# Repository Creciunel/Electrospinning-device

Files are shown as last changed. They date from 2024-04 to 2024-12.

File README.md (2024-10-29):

<h2>Contents</h2>

<ul>
  <li><a href="#features">Features</a></li>
  <li><a href="#hardware-setup">Hardware Setup</a></li>
  <li><a href="#software-board-code">Software Board Code</a></li>
  <li><a href="#usage">Usage</a></li>
  <li><a href="#contributing">Contributing</a></li>
  <li><a href="#license">License</a></li>
</ul>

<h1>Electrospinning Device based on ATMEGA2560</h1>

<p>This repository contains the source code, hardware schematics, and documentation for a device designed to facilitate the electrospinning process using the ATMEGA2560 microcontroller (Arduino Mega).</p>

<h2 id="features">Features</h2>

<p>The device provides the following features:</p>
<ul>
  <li>Control and monitoring with BME280 sensor of temperature, pressure, humidity. And adjustable flow rate.</li>
  <li>FreeRTOS based task scheduler for easier and more efficient task management.</li>
  <li>High voltage source for electrospinning process.</li>
  <li>LCD display for monitoring.</li>
  <li>Motor for controlling the flow of the syringe. using driver TB6600.</li>
  <li>Encoder for user interaction.</li>
</ul>

<h2 id="hardware-setup">Hardware Setup</h2>

<table>
  <tr>
    <th>
      <p>The hardware setup consists of the following components:</p>
    </th>
  <tr>
    <td>
      <ul>
        <li><b>The high voltage power supply</b> generates the high voltage needed for the electrospinning process. It provides a stable and adjustable voltage source to create the electrostatic field required to draw the polymer solution into nanofibers.</li>
        <li><b>Varistor and Transformer</b> convert the high voltage to the voltage required for electrospinning.</li>
        <li><b>Multiplier/Rectifier</b> converts the voltage to the voltage required for the motor.</li>
      </ul>
    </td>
  </tr>
  <tr>
    <td>
      <h3>Comand Board</h3>
        <ul>
        <li><b>MCU</b> ATMEGA2560 (Mega 2560)</li>
        <li><b>Encoder</b> For seting the flow rate, starting and stopping the motor, and opening screen with sensor values.</li>
        <li><b>LCD Display</b> Show sensor values.</li>
        <li><b>TB6600</b> Stepper motor driver.</li>
        <li><b>Motor</b> Stepper motor for controlling the flow of the syringe.</li>
        <li><b>BME280</b> Sensor for monitoring temperature, pressure, and humidity.</li>
        <li><b>Power Supply</b> MCU power supply.</li>
      </ul>
    </td>
  </tr>
</table>
<ul>
  <li>See more about <a href="/Hardware/README.md">hardware Setup</a></li>
</ul>

<h2 id="software-board-code">Software Board Code</h2>
<ul>
  <li>See more about <a href="/Software/Electrospining/README.md">software board code.</a></li>
</ul>

<h2>Usage</h2>

<p>To use the electrospinning device:</p>
<ol>
  <li>Connect the high voltage source to 220V.</li>
  <li>Connect the Arduino Mega to the components and upload the provided source code.</li>
  <li>Use the LCD screen with encoder to control and monitor the electrospinning process.</li>
  <li>Adjust the settings as needed and start the electrospinning process.</li>
  <li>Monitor the output and make adjustments as necessary.</li>
</ol>

<h2>Contributing</h2>
<p>Contributions to this project are welcome. Please fork the repository, make your changes, and submit a pull request.</p>

<h2>License</h2>
<p>This project is licensed under the <a href="LICENSE">MIT License</a>.</p>

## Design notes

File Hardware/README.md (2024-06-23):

# Electrospinning Device based on Arduino Mega

## High voltage result and schematics

### Reult

<p> The result of the electrospinning process is accesible on link below. </p>
<a href="https://docs.google.com/spreadsheets/d/1FEkuDaI_2rEFF1M06S9z06Yd7cQ-smT4pYeCvJsIN_U/edit?usp=sharing">Value on testing process</a>

### Schematics

## Hardware Connection

<table style="border: none;">
  <tr>
    <h3>Display</h3>
    <!-- display charaters -->
    <ul>
        <li> Examples of <a href="https://github.com/WeActStudio/WeActStudio.TFT-LCD-Module/tree/master/Examples">code</a> </li>
        <li> <a href="https://github.com/WeActStudio/WeActStudio.TFT-LCD-Module">WeActStudio.TFT-LCD-Module</a> </li>
    </ul>
    <td style="border: none; text-align: left;">
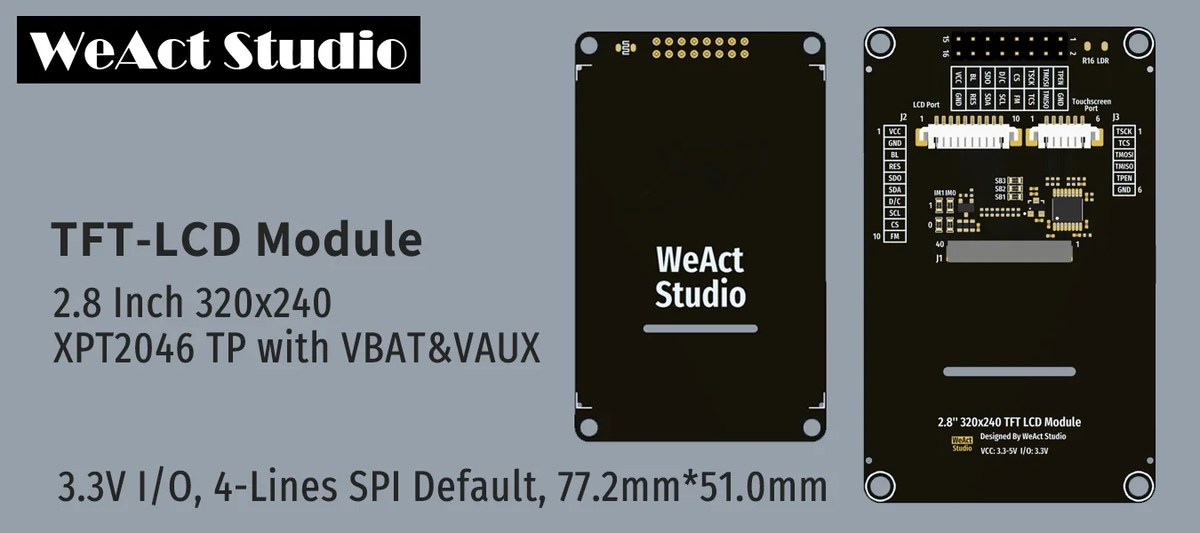
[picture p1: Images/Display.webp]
Display
      
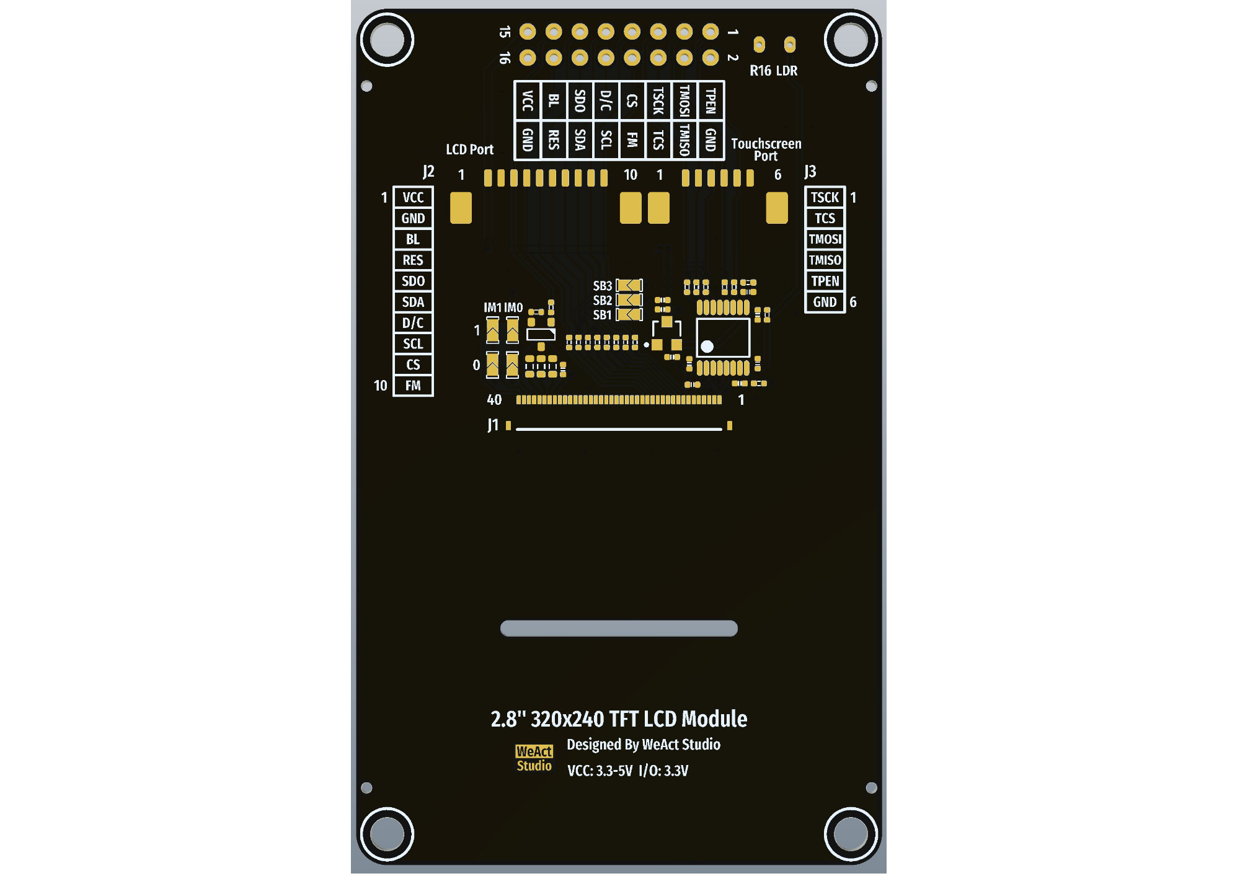
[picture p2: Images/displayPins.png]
pinout
      
      <!-- https://github.com/WeActStudio/WeActStudio.TFT-LCD-Module -->
      <table>
        <tr>
            <th>Arduino Pins</th>
            <th>ILI9341 Pins</th>
            <th></th>
            <th>Arduino Pins</th>
            <th>TouchScreen Pins</th>
        </tr>
        <tr>
            <td>3.3V or 5V</td>
            <td>VCC</td>
            <td></td>
            <td>13</td>
            <td>TSCK (SCK)</td>
        </tr>
        <tr>
            <td>GND</td>
            <td>GND</td>
            <td></td>
            <td>14</td>
            <td>TCS (CS)</td>
        </tr>
        <tr>
            <td>6</td>
            <td>BL</td>
            <td></td>
            <td>15</td>
            <td>TMOSI (MOSI)</td>
        </tr>
        <tr>
            <td>7</td>
            <td>RES</td>
            <td></td>
            <td>12</td>
            <td>TMISO (MISO)</td>
        </tr>
        <tr>
            <td>12</td>
            <td>SDO (MISO)</td>
            <td></td>
            <td>17</td>
            <td>TPEN (Touch Interrupt)</td>
        </tr>
        <tr>
            <td>11</td>
            <td>SDA (MOSI)</td>
            <td></td>
            <td>GND</td>
            <td>GND</td>
        </tr>
        <tr>
            <td>8</td>
            <td>D/C</td>
            <td></td>
            <td></td>
            <td></td>
        </tr>
        <tr>
            <td>13</td>
            <td>SCL (SCK)</td>
            <td></td>
            <td></td>
            <td></td>
        </tr>
        <tr>
            <td>9</td>
            <td>CS</td>
            <td></td>
            <td></td>
            <td></td>
        </tr>
        <tr>
            <td>Not connected</td>
            <td>FM</td>
            <td></td>
            <td></td>
            <td></td>
    </table>
 <!-- <table>
    <tr>
          <th>Arduino Pins</th>
          <th>ILI9341 Pins</th>
        </tr>
        <tr>
          <td>53</td>
          <td>TFT_CS</td>
        </tr>
        <tr>
          <td>46</td>
          <td>TFT_DC</td>
        </tr>
        <tr>
          <td>51</td>
          <td>TFT_MOSI</td>
        </tr>
        <tr>
          <td>52</td>
          <td>TFT_SCLK</td>
        </tr>
        <tr>
          <td>47</td>
          <td>TFT_RST</td>
        </tr>
        <tr>
          <th>Arduino Pins</th>
          <th>TouchScreen Pins</th>
        </tr>
        <tr>
          <td>A14</td>
          <td>YP</td>
        </tr>
        <tr>
          <td>A15</td>
          <td>XM</td>
        </tr>
        <tr>
          <td>48</td>
          <td>YM</td>
        </tr>
        <tr>
          <td>49</td>
          <td>XP</td>
        </tr>
      </table> -->
    </td>
  </tr>

  <tr>
    <h3>Motor</h3>
    <td style="border: none; text-align: left;">
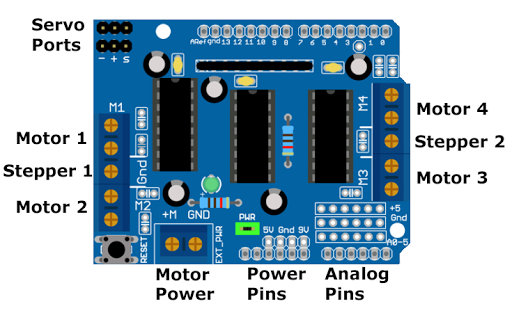
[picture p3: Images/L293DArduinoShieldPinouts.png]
L293D Motor Driver Shield
          
      <table>
        <tr>
          <th>Arduino Pins</th>
          <th><a href="https://github.com/adafruit/Adafruit_Motor-Shield-v1/blob/master/mshieldv12schem.png">L293D Motor Driver Shield</a></th>
          <th></th>
          <th>Motor sheld sheft registers 74HCT595</th>
          <th>Pin</th>
        </tr>
        <tr>
          <td>11</td>
          <td>Motor 1</td>
          <td></td>
          <td>MOTOR1_A</td>
          <td>2</td>
        </tr>
        <tr>
          <td>3</td>
          <td>Motor 2</td>
          <td></td>
          <td>MOTOR1_B</td>
          <td>3</td>
        </tr>
        <tr>
          <td>5</td>
          <td>Motor 3</td>
          <td></td>
          <td>MOTOR2_A</td>
          <td>1</td>
        </tr>
        <tr>
          <td>6</td>
          <td>Motor 4</td>
          <td></td>
          <td>MOTOR2_B</td>
          <td>4</td>
        </tr>
        <tr>
          <td>9</td>
          <td>Servo 1</td>
          <td></td>
          <td>MOTOR3_A</td>
          <td>5</td>
        </tr>
        <tr>
          <td>10</td>
          <td>Servo 2</td>
          <td></td>
          <td>MOTOR3_B</td>
          <td>7</td>
        </tr>
        <tr>
          <td>4, 7, 8, 12</td>
          <td>Shift registers</td>
          <td></td>
          <td>MOTOR4_A</td>
          <td>0</td>
        </tr>
        <tr>
          <td>2 and 13, Analog A0 to A5</td>
          <td>Not Connected</td>
          <td></td>
          <td>MOTOR4_B</td>
          <td>6</td>
        </tr>
      </table>

### ADC Analog-to-Digital Converter

It is connected to pin A8 or as number 62.

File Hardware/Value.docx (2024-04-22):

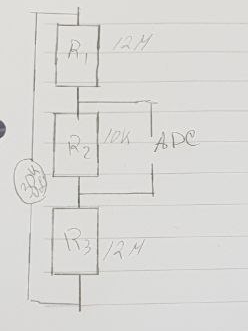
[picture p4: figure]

V_(out) = 30kV

V_(in) = 24V A_(in) = 6.25A P = 150W

P = I^2 ·R

I_(tot) = 30kV/200Mῼ = 150µA

P_1 =P_3 = (150 µA )^2 · 100Mῼ = 2.25W

P_2 = (150 µA )^2 · 10kῼ = 225µW

V_(R1) = 150 µA · 100Mῼ = 15V

V_(R2) = 150 µA · 10kῼ = 1.5V

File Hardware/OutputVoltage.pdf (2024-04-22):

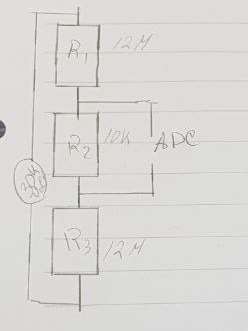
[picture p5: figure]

V= 30kV

V= 24V A= 6.25A P = 150W

P = I

- R
I= 30kV/200Mῼ = 150µA

P = P= (150 µA )
- 100Mῼ = 2.25W

P= (150 µA )
- 10kῼ = 225µW

V= 150 µA · 100Mῼ = 15V

V= 150 µA · 10kῼ = 1.5V

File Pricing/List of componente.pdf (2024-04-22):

NR | What we actual have | Price
1 | Arduino Mega | | Zero - from diferent project
2 | ZVS Driver | mkrid=707-127634-2357-0&ssspo=ux51k_mbsss&sssrc=4429486&ssuid=lz6subesszy&var= | 11.91 Euro - with Postage
3 https://sl.aliexpress.ru/p?key=gbbROf2 | ILI9341 Display | | 205 Lei - with Postage
4 https://sl.aliexpress.ru/p?key=QlbROZx | L293D Sheeld driver | | 64 Lei - with Postage
5 | Rezistors
6 | Steper Motoare
7 From old TV | FlyBack Transformer
8 | Source
9

Vlad
Cătălin

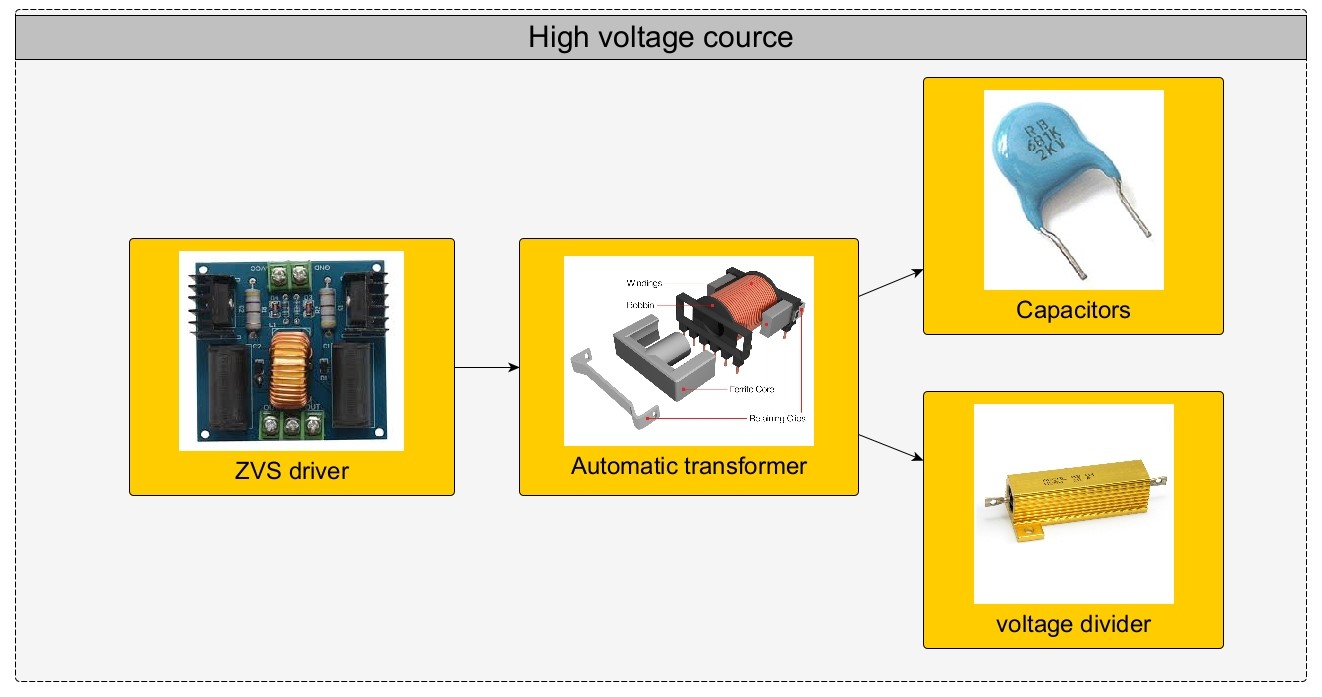
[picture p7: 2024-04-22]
Images/HVS.jpg

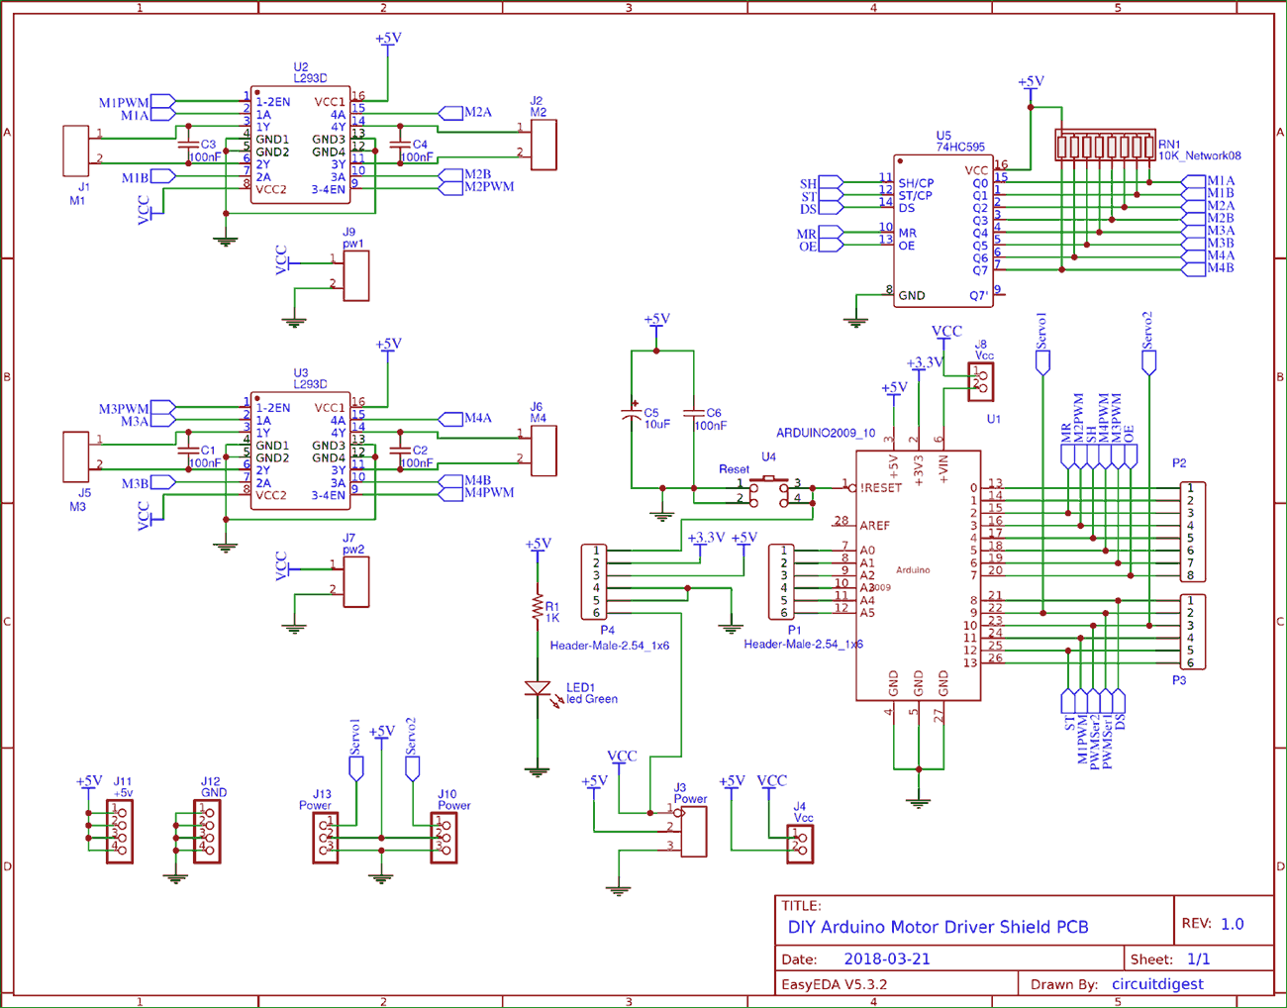
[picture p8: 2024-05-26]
Images/Circuit-Diagram-for-DIY-Arduino-Motor-Driver-Shield-PCB_0.png

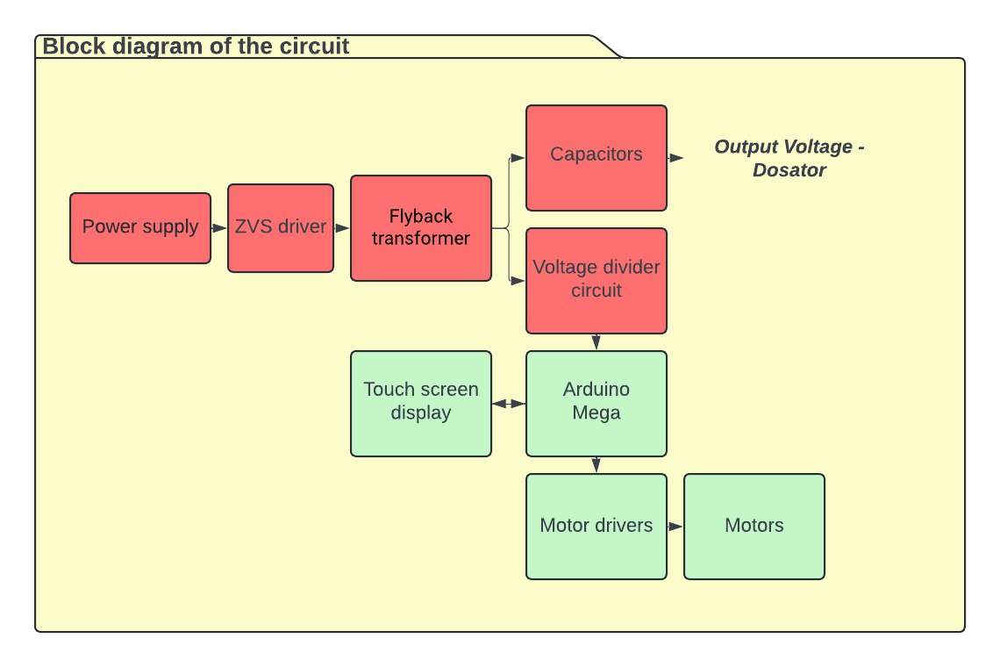
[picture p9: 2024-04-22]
Images/Block-diagram.jpg

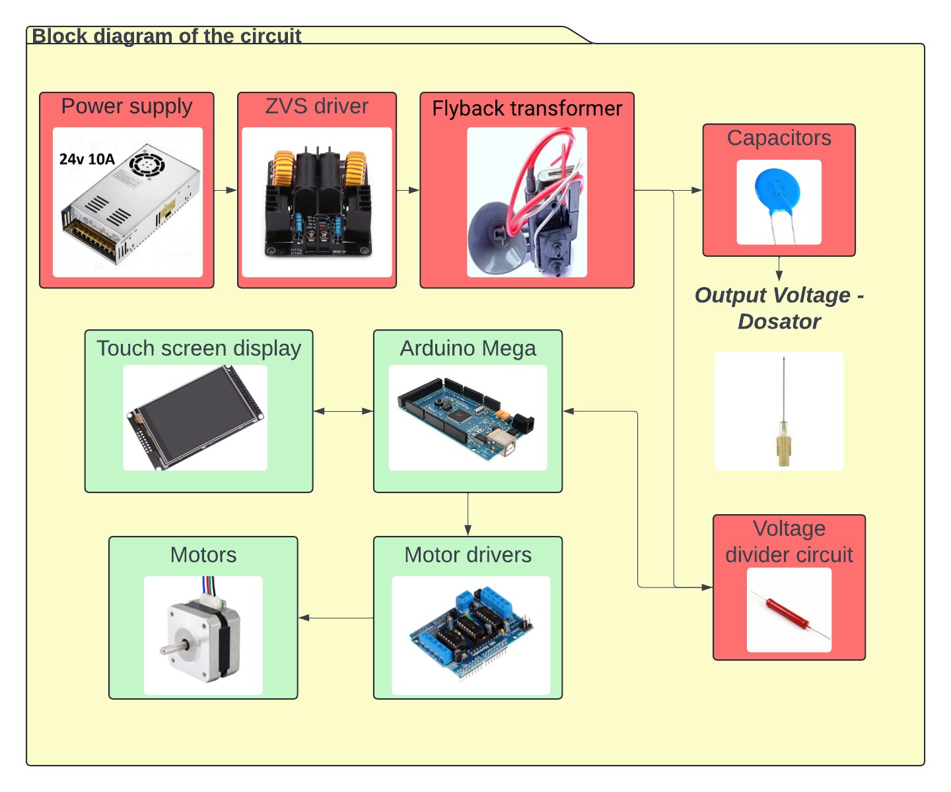
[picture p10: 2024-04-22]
Images/Block-diagram1.jpg

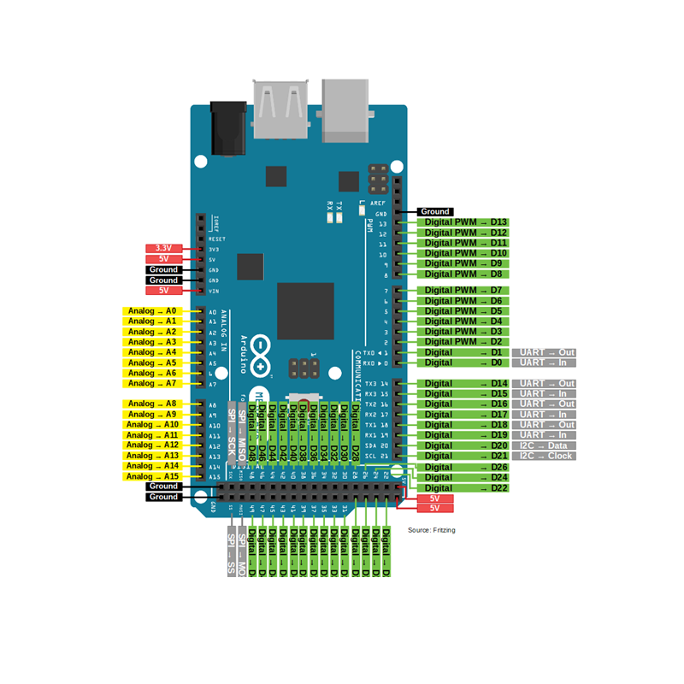
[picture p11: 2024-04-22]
Images/Mega-Pin-Configuration.webp

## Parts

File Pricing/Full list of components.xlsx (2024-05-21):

Lista componentelor pentru dispozitiv de electrospinning
Nr. | Componentul | Pretul/unitate € | Descriere | Link | Pretul/unitate lei | Descriere | Link
1 | Stm32F411RE / Arduino Mega | 12.64€ | 12,64 € / 44,24 € | NUCLEO-F411RE STMicroelectronics | Development Boards, Kits, Programmers | DigiKey https://www.digikey.de/en/products/detail/arduino/A000067/2639006 | 200 | 200 mega 450 stm
2 | L293D Sheeld driver | 2.02 |  | https://www.ebay.de/itm/232477849395?ssspo=vdx7hCYXSwa&sssrc=2047675&ssuid=&widget_ver=artemis&media=COPY | 57 | include livrarea | https://sl.aliexpress.ru/p?key=SwrKOix
3 | Display Module ILI9341 | 15.78 |  | https://www.ebay.de/itm/174940725612?ssspo=p795EKDWQse&sssrc=2047675&ssuid=&widget_ver=artemis&media=COPY | 201 | include livrarea | https://sl.aliexpress.ru/p?key=IUrKOo7
4 | ZVS Driver | 6.98 | $ | https://www.ebay.com/itm/202566983000?ssspo=9I5Sp2lVTH-&sssrc=2047675&ssuid=&widget_ver=artemis&media=COPY | 274 | include livrarea 179 lei pentru 150W | https://sl.aliexpress.ru/p?key=uGrKOuk https://sl.aliexpress.ru/p?key=1rrKOMT
5 | Sursa
6 | Rezistente | 9.03 | 2 - 30M 1 - 10K $ | https://www.ebay.com/itm/233927859278?var=533575887861 | 210 | cu livrare, bucata | https://sl.aliexpress.ru/p?key=pgrKOR2
7 | Steper Motoare |  | 2
8 | Condensatoare | 6.26 | $ | 50KV 102 222 561 K High-voltage Ceramic Capacitor Capacitors 1000 2200 pF | eBay (https://www.ebay.com/itm/192140338362?var=492053965553) | 53 | cu livrare | https://sl.aliexpress.ru/p?key=TqrKO2G
9 | Fire |  | Pentru tensiune inalta
10 | Colector |  | Cilindru din metal
11 | FlyBack Transformer
12 | Diode | 0.18€ | 1N4007-T | 1N4007-T Diodes Incorporated | Discrete Semiconductor Products | DigiKey (https://www.digikey.de/en/products/detail/diodes-incorporated/1N4007-T/607) | 106 | cu livrare | https://sl.aliexpress.ru/p?key=nArKOXt
13 | Pneumatic Switch | 8.35 |  | https://www.ebay.de/itm/325971069536?ssspo=D0jJRbu4QUO&sssrc=2047675&ssuid=&widget_ver=artemis&media=COPY | 80 | cu livrare | https://sl.aliexpress.ru/p?key=bLrKOCn
14 | Voltmeter | 10 | $ | 1*Class 2.5 DC 0-100KV Range Analog Voltage Voltmeter Panel Meter 69C17 New | eBay (https://www.ebay.com/itm/162136923463?itmmeta=01HPKKFBNWRAVJCB9RCXWGVMQW) | 244 | cu livrare | https://sl.aliexpress.ru/p?key=hKrKOXH
15 | DC/DC convertot |  | 600W 10A | https://aliexpress.ru/item/1005006068517950.html?sku_id=12000035582178214 | 100
 | Total | 71.24€ |  |  | 1525
 | bolt pentru seringa | 15 euro |  | https://robotica.md/surub-trapezoidal

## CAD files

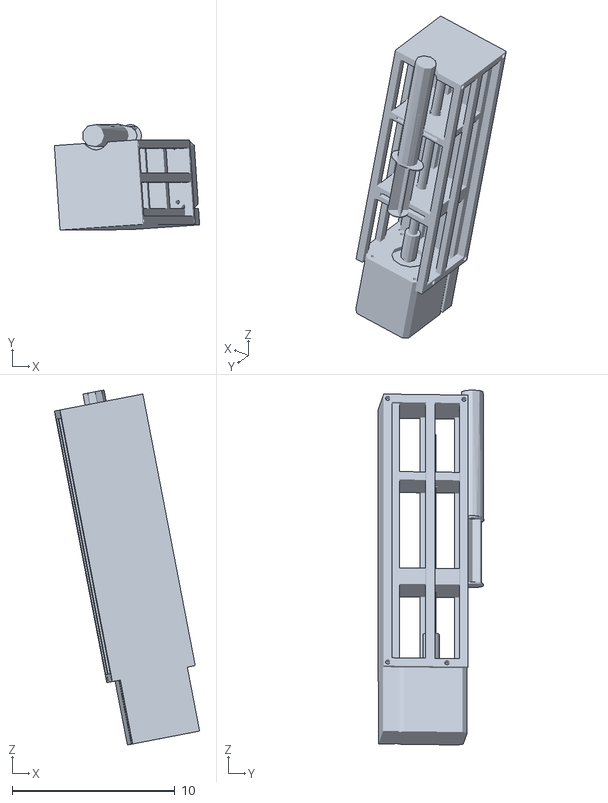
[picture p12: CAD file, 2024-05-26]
Hardware/syringe/Assembly.stl
8.93 x 6.52 x 21.8

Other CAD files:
Hardware/syringe/Assembly.iam
Hardware/syringe/OldVersions/Assembly test.0002.iam
Hardware/syringe/OldVersions/Assembly.0025.iam
Hardware/syringe/OldVersions/attachment motor.0011.ipt
Hardware/syringe/OldVersions/gaica cu suportul.0004.ipt
Hardware/syringe/OldVersions/gaica.0002.ipt
Hardware/syringe/OldVersions/lateral suport 2.0001.ipt
Hardware/syringe/OldVersions/lateral suport.0012.ipt
Hardware/syringe/OldVersions/motor-01.0001.ipt
Hardware/syringe/OldVersions/motor.0001.ipt
Hardware/syringe/OldVersions/seringa inside.0001.ipt
Hardware/syringe/OldVersions/seringa outer.0001.ipt
Hardware/syringe/OldVersions/sina.0006.ipt
Hardware/syringe/OldVersions/suport continuare seringa.0004.ipt
Hardware/syringe/OldVersions/suport cu rulment pentru tija.0006.ipt
Hardware/syringe/OldVersions/tija filet.0007.ipt
Hardware/syringe/attachment motor.ipt
Hardware/syringe/gaica cu suportul.ipt
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

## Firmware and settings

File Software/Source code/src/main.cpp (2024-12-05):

#include "main.h"

void vTaskEncoder(void *pvParameters);
void vTaskMotor(void *pvParameters);
void vTaskLCD(void *pvParameters);
void vTaskCommunication(void *pvParameters);
void vTaskSensor(void *pvParameters);

// Motor constants
float motor1Speed = 0.1;      // Schimbat la float pentru a permite valori fracționare
uint8_t motor2Speed = 25;     // Viteza motorului
uint8_t motorDirection = LOW; // Direcția motorului

// Transformer variables
uint8_t pwmValue = 0;

float voltage = 0.0;
float temperature = 0.0;
float humidity = 0.0;
float pressure = 0.0;

// Encoder și LCD
// Create a global pointer for the encoder object
Encoder enc(CLK, DT, SW, TYPE1);
LiquidCrystal_I2C lcd(ADDRESS, 16, 2);
MWCSTEPPER tb6600_m1(ENA_PIN1, DIR_PIN1, PUL_PIN1); // Inițializează driverul motorului

AF_DCMotor motor(1);

struct Flag
{
    uint8_t start = 0; // Starea de start/stop
} flag;

void setup()
{
    Serial.begin(115200);

    wdt_enable(WDTO_2S);

    // Crearea sarcinilor
    xTaskCreate(vTaskEncoder, "Encoder Task", 512, NULL, 1, NULL);
    xTaskCreate(vTaskMotor, "Motor Task", 256, NULL, 1, NULL);
    xTaskCreate(vTaskLCD, "LCD Task", 256, NULL, 1, NULL);
    xTaskCreate(vTaskCommunication, "Communication Task", 128, NULL, 1, NULL);
    xTaskCreate(vTaskSensor, "Sensor Task", 256, NULL, 1, NULL);

    // Pornește scheduler-ul FreeRTOS
    vTaskStartScheduler();

    // Setare Timer0 pentru a obține o frecvență de aproximativ 7kHz
    pinMode(EN_HIGH_VOLTAGE, OUTPUT);

    // Initializarea LCD
    lcd.init();
    lcd.backlight();

    motor.setSpeed(motor2Speed);
    motor.run(RELEASE);
}

void loop() {}

void vTaskLCD(void *pvParameters)
{
    // Initializarea LCD
    lcd.init();
    lcd.backlight();

    for (;;)
    {
        wdt_reset();

        lcd.clear();

        switch (currentState)
        {
        case MAIN_MENU:
            lcd.setCursor(0, 0);
            lcd.print("Electrospinning");
            lcd.setCursor(11, 1);
            lcd.print("setup");
            break;

        case SELECT_DIRECTION:
            lcd.setCursor(0, 0);
            lcd.print("Direction:");
            lcd.setCursor(0, 1);
            lcd.print(motorDirection == LOW ? "Forward" : "Backward");
            break;

        case SELECT_MOTOR1_SPEED:
            lcd.setCursor(0, 0);
            lcd.print("Motor 1 speed:");
            lcd.setCursor(0, 1);
            lcd.print(String(motor1Speed, 2)); // Afișează cu două zecimale
            break;

        case SELECT_MOTOR2_SPEED:
            lcd.setCursor(0, 0);
            lcd.print("Motor 2 speed:");
            lcd.setCursor(0, 1);
            lcd.print(int(motor2Speed)); // Afișează viteza curentă
            break;

        case SENSOR_VALUES:
            lcd.setCursor(0, 0);
            lcd.print("V_out:" + String(int(voltageValue(analogRead(ADC_PIN)) / 1000.0))+"kV");
            lcd.setCursor(0, 1);
            lcd.print("T:" + String((int)(temperature)));
            lcd.setCursor(5, 1);
            lcd.print("H:" + String((int)(humidity)));
            lcd.setCursor(10, 1);
            lcd.print("P:" + String((int)(pressure)));
            lcd.setCursor(11, 0);
            lcd.print(flag.start ? "Start" : "Stop");
            break;
        }

        vTaskDelay(500 / portTICK_PERIOD_MS); // Actualizează LCD-ul la fiecare jumătate de secundă
    }
}

void vTaskMotor(void *pvParameters)
{
    tb6600_m1.init();
    for (;;)
    {
        // motor2Speed = map(motor2Speed, 0, 200, 0, 255);

        tb6600_m1.set(motorDirection == HIGH ? CLOCKWISE : COUNTERCLOCKWISE, motor1Speed, THIRTYTWO_STEP);
        if (flag.start)
        {
            tb6600_m1.run(); // Rotește motorul la viteza setată
            motor.setSpeed(motor2Speed);
            motor.run(motorDirection == HIGH ? FORWARD : BACKWARD);
        }
        else
        {
            tb6600_m1.active(false); // Oprește motorul
            motor.run(RELEASE);
        }
        wdt_reset(); // Resetare watchdog

        vTaskDelay(20 / portTICK_PERIOD_MS); // Delay pentru reacții rapide
    }
}

void vTaskEncoder(void *pvParameters){
    for (;;)
    {
        enc.tick();

        if (enc.isSingle())
        {
            // Schimbă starea meniului la apăsare
            switch (currentState)
            {
            case MAIN_MENU:
                currentState = SELECT_DIRECTION;
                Serial.println("Select Direction");
                break;
            case SELECT_DIRECTION:
                currentState = SELECT_MOTOR1_SPEED;
                Serial.println("Select motor 1 speed");
                break;
            case SELECT_MOTOR1_SPEED:
                currentState = SELECT_MOTOR2_SPEED;
                Serial.println("Select motor 2 speed");
                break;
            case SELECT_MOTOR2_SPEED:
                currentState = MAIN_MENU;
                Serial.println("Back to Main Menu");
                break;
            case SENSOR_VALUES:
                currentState = MAIN_MENU;
                Serial.println("Back to Main Menu");
                break;
            }
        }
        else if (enc.isDouble())
        {
            // Resetare la starea inițială
            currentState = SENSOR_VALUES;
            Serial.println("Sensor Values");

            if (flag.start)
            {
                flag.start = false;
                Serial.println("Stop");
                digitalWrite(EN_HIGH_VOLTAGE, LOW);
            }
            else
            {
                flag.start = true;
                Serial.println("Start");
                digitalWrite(EN_HIGH_VOLTAGE, HIGH);
            }
        }
        else if (currentState == SELECT_DIRECTION)
        {
            if (enc.isRight())
            {
                motorDirection = LOW; // Forward
                Serial.println("Direction: Forward");
            }
            else if (enc.isLeft())
            {
                motorDirection = HIGH; // Backward
                Serial.println("Direction: Backward");
            }
        }
        else if (currentState == SELECT_MOTOR1_SPEED)
        {
            if (enc.isLeft())
            {
                // Crește viteza
                if (motor1Speed >= 1)
                {
                    motor1Speed++; // Crește cu 1 dacă este >= 1
                    if (motor1Speed > 100)
                        motor1Speed = 100; // Limitează viteza maximă
                }
                else if (motor1Speed >= 0.1 && motor1Speed < 1)
                {
                    motor1Speed += 0.1; // Crește cu 0.1 dacă este între 0.1 și 1
                }

                Serial.println("Speed: " + String(motor1Speed, 2)); // Afișează cu două zecimale
            }
            else if (enc.isRight())
            {
                // Scade viteza
                if (motor1Speed >= 1)
                {
                    motor1Speed--;                                      // Scade cu 1 dacă este >= 1
                    Serial.println("Speed: " + String(motor1Speed, 2)); // Afișează cu două zecimale
                }
                else if (motor1Speed < 1 && motor1Speed >= 0.1)
                {
                    motor1Speed -= 0.1; // Scade cu 0.1 dacă este între 0.1 și 1
                    if (motor1Speed < 0.1)
                        motor1Speed = 0.1; // Limitează viteza minimă la 0.1

                    Serial.println("Speed: " + String(motor1Speed, 2)); // Afișează cu două zecimale
                }
            }
        }
        else if (currentState == SELECT_MOTOR2_SPEED)
        {
            if (enc.isLeft())
            {
                motor2Speed++;
                if (motor2Speed > 200)
                    motor2Speed = 200; // Limitează viteza maximă
                Serial.println("Speed: " + String(motor2Speed));
            }
            else if (enc.isRight())
            {
                motor2Speed--;
                if (motor2Speed < 1)
                    motor2Speed = 1; // Limitează viteza minimă
                Serial.println("Speed: " + String(motor2Speed));
            }
        }

        wdt_reset(); // Resetare watchdog

        vTaskDelay(30 / portTICK_PERIOD_MS); // Întârziere pentru reacții rapide
    }
}

void vTaskCommunication(void *pvParameters)
{
    Serial.println("System Initialized\r\n s - start, d - direction, m - motor 1 speed, M - motor 2 speed\r\n");

    for (;;)
    {
        if (Serial.available() > 0)
        {
            char key = Serial.read();
            int val = Serial.parseInt();

            switch (key)
            {
            case 's':
                flag.start = val;
                digitalWrite(ENA_PIN1, flag.start ? LOW : HIGH); // Activează/dezactivează driverul
                digitalWrite(ENA_PIN2, flag.start ? LOW : HIGH);
                digitalWrite(EN_HIGH_VOLTAGE, flag.start ? HIGH : LOW);
                break;
            case 'd':
                motorDirection = val ? HIGH : LOW;
                break;
            case 'm':
                motor1Speed = val;
                break;
            case 'M':
                motor2Speed = val;
                break;
            default:
                Serial.println("Wrong command! key: " + String(key) + ", val: " + String(val));
                break;
            }
        }

        wdt_reset();

        vTaskDelay(100 / portTICK_PERIOD_MS);
    }
}

void vTaskSensor(void *pvParameters)
{
    Adafruit_BME280 bme; // Crearea obiectului BME280

    if (!bme.begin(0x76))
    { // Verifică adresa I2C
        Serial.println("Could not find a valid BME280 sensor, check wiring!");
        vTaskDelete(NULL); // Oprește task-ul dacă senzorul nu este găsit
    }

    for (;;)
    {
        // Citirea valorilor de la BME280
        temperature = bme.readTemperature(); // Asigură-te că ai inițializat senzorul BME280
        humidity = bme.readHumidity();
        pressure = bme.readPressure() / 100.0F; // Convertim la hPa

        // Afișează valorile cu o singură zecimală
        // Serial.print("Temperature: ");
        // Serial.print((int)(temperature * 10) / 10.0); // Rotunjire la o zecimală
        // Serial.print(" °C, Pressure: ");
        // Serial.print((int)(pressure * 10) / 10.0); // Rotunjire la o zecimală
        // Serial.print(" hPa, Humidity: ");
        // Serial.print((int)(humidity * 10) / 10.0); // Rotunjire la o zecimală
        // Serial.println(" %");

        wdt_reset();

        vTaskDelay(2000 / portTICK_PERIOD_MS); // Actualizează datele la fiecare 2 secunde
    }
}

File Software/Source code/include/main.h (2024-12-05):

#include <Wire.h>
#include <LiquidCrystal_I2C.h>
#include <Arduino.h>

#include <Arduino_FreeRTOS.h>

#include <Adafruit_Sensor.h>
#include <Adafruit_BME280.h>

#include <AFMotor.h>

#include <mwc_stepper.h>
#include <GyverEncoder.h>

#include <avr/wdt.h>


#define ADDRESS          0x27 // I2C address
#define SCL_PIN          21
#define SDA_PIN          20

// Definește pinii pentru TB6600 Stepper motor 1
#define DIR_PIN1          46    // DIR+
#define PUL_PIN1          44    // PUL+
#define ENA_PIN1          48   // ENA+

// Define pinii pentru TB6600 Stepper motor 2
#define DIR_PIN2          47    // DIR+
#define PUL_PIN2          45    // PUL+
#define ENA_PIN2          49   // ENA+

#define CLOCKWISE          1
#define COUNTERCLOCKWISE   0

#define FULL_STEP          200 
#define HALF_STEP          400 
#define QUARTER_STEP       800
#define EIGHTH_STEP        1600
#define SIXTEENTH_STEP     3200
#define THIRTYTWO_STEP     6400

// ADC constants
#define ADC_PIN           A9 // ADC pin
#define ADC_RESOLUTION    5.0 / 1024.0
#define R2                10151.5 // R2 resistor value in ohms
#define R1                48300000 // R1 resistor value in ohms
#define R3                7200 // R3 resistor value in ohms 
#define R4                1500 // R4 resistor value in ohms

// Calculate voltage gain between two resistors
#define VOLTAGE_GAIN ((R1 + R2) / R2)

// Time constants
#define PRINT_DELAY           2000
#define COMMUNICATION_DELAY   100
#define ENCODER_DELAY         100

// Helper functions
#define MillisecondsToMinutes(milliseconds) ((milliseconds) / 60000.0)

// Encoder constants
#define CLK               26
#define DT                24
#define SW                22

// Relay constants
#define RELAY             30
#define RELAY1            32

#define EN_HIGH_VOLTAGE   13 

// display state
enum MenuState {
    MAIN_MENU,
    SELECT_DIRECTION,
    SELECT_MOTOR1_SPEED,
    SELECT_MOTOR2_SPEED,
    SENSOR_VALUES,
};

MenuState currentState = MAIN_MENU;

int voltageValue(uint16_t adcValue)
{
    // Calculate Vout1 from the first divider
    float Vout1 = (ADC_RESOLUTION * adcValue) * ((R1 + R2) / R2);

    // Calculate Vout2 from the second divider
    float Vout2 = Vout1 * ((R3 + R4) / R4);

    return Vout2; // Return the final scaled voltage
}

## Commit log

2024-04-12 Update ADC function and Serial protocol
2024-04-15 Update motor description
2024-05-21 200 step motor
2024-05-21 add motor test
2024-05-22 add adc to test
2024-05-23 test motor and adc
2024-05-23 add arduino uno support
2024-05-23 add motor setings
2024-05-23 stop motor
2024-05-23 stop motor and run Uno
2024-05-23 update motor
2024-05-24 add esp32 s3 test
2024-05-24 motor stom message
2024-05-26 -update folders
    [Assembly test.0002.iam, Assembly.0025.iam, Assembly.iam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]
2024-10-14 add encoder, display, code
2024-10-14 add motor function
2024-10-24 Add secod motor for colector
2024-12-05 Update voltmater
